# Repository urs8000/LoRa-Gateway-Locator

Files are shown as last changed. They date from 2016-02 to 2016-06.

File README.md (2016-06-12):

# LoRa-Gateway-Locator
This Node sends its position in selectable periods to all reachable gateways.
Analysing the received data on node API, where the gateway EUID is shown, 
a dotted map with the coverage of each gateway could be drawn.
made by https://github.com/gonzalocasas/ttn-coverage-tracker
**The data were also shown on JPMejier's http://ttnmapper.org/**

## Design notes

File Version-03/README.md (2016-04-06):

Based on Version 01/02
- Teensy 3.2
- GPS u-blox PAM-7Q with battary backup
- RFM95W (LoRa Radio 868MHz)
- OLED display (128x64) look careful when ordering. some have Vcc ans GND switched!
- navigation switches

this Version (03) added the following features
- debug/status LED (Common Anode RGB-LED, "Piranha diffused")
- PPS LED  (pulse per second)
- board mounted switches (wires could be connected for box mounted ones instead of them)
- second antenna connector (u.fl)
- GPS backup battery (CR1220)
- OpenLog SDcard based logger, connected via Serial3
  all sent positions will be logged, so it could be compared from where no connection to a given gateway could be established.

some explanations to the power supply:
getting the most out of 3 x 1.5V AA batteries and having stable 5V therefor I've added a xV to 5V step-up boost converter
The suggested Pololu step-up does not work correctly in contrary to the specification.
So I changed to another (bulkier) type found at eBay ( DC-DC Boost Converter Step Up 1-5V to 5V 500mA Module ) 
Because the layout is totally different, you have to solder it inbetween the batter case and the input pins and to bridge Vin-Vout.
If you plan to use a 5V power bank you just can bridge Vin and Vout and connect your supply instead of batteries to JPOWER

Tested on final boards, made by ITEAD Studio

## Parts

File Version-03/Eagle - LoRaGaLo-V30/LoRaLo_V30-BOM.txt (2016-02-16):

Stückliste exportiert aus C:/Users/urs/Documents/_Development/Eagle_Projects/LoRaLo-3/LoRaLo_V30.sch am 15.02.2016 23:42

Part                 Value           Device            Package         Description                                                                  MF MPN OC_FARNELL OC_NEWARK PROD_ID    VALUE
ANTENNA-(EDGE-MOUNT) SMA_EDGE        SMA_EDGE          SMA-EDGE        SMA Antenna Connector                                                                                                    
ANTENNA-(U.FL)       U.FL            U.FL              U.FL            SMD antenna connector- WRL-09144                                                                         CONN-09193 U.FL 
C1                   100u            CPOL-EUD          PANASONIC_D     POLARIZED CAPACITOR, European symbol                                                                                     
C4                   100n            C-EUC1206         C1206           CAPACITOR, European symbol                                                                                               
C7                   100u            CPOL-EUD          PANASONIC_D     POLARIZED CAPACITOR, European symbol                                                                                     
C8                   100u            CPOL-EUD          PANASONIC_D     POLARIZED CAPACITOR, European symbol                                                                                     
CR1220                               CH291-1220LF      CH291-1220LF    Battery Holder, SMT, 12mm                                                                                                
GPS-U-BLOX-PAM7M     U-BLOX-PAM-7Q   U-BLOX-PAM-7Q     U-BLOX-PAM-7Q                                                                                                                            
JPOWER                               M-1X02-SIP-100-40 SIP-100-02-40   MALE HEADER                                                                                                              
LED1                 RED             LED1206           LED-1206        LEDs                                                                                                                     
LED2                 white           LED1206           LED-1206        LEDs                                                                                                                     
OLED_128X64                          OLED_128X64       OLED_128X64                                                                                                                              
OPENLOG-MODULE                       MA06-1            MA06-1          PIN HEADER                                                                          unknown    unknown                   
P1                                   1,6/0,8           1,6/0,8         THROUGH-HOLE PAD                                                                                                         
P2                                   1,6/0,8           1,6/0,8         THROUGH-HOLE PAD                                                                                                         
P3                                   1,6/0,8           1,6/0,8         THROUGH-HOLE PAD                                                                                                         
R1                   130             RESISTOR1206      1206            Resistor                                                                                                                 
R2                   47              RESISTOR1206      1206            Resistor                                                                                                                 
R3                   47              RESISTOR1206      1206            Resistor                                                                                                                 
R4                   270             R-EU_M1206        M1206           RESISTOR, European symbol                                                                                                
R5                   4.7k            R-EU_M1206        M1206           RESISTOR, European symbol                                                                                                
R6                   4.7k            R-EU_M1206        M1206           RESISTOR, European symbol                                                                                                
R7                   270             R-EU_M1206        M1206           RESISTOR, European symbol                                                                                                
RGB-LED              LED_PIRANHA_5MM LED_PIRANHA_5MM   LED_PIRANHA_5MM High-brightness RGB through-hole LED, similar to that used in the Shiftbrite                                             
S-DWN                                TAC_SWITCHPTH     TACTILE-PTH     Momentary Switch                                                                                                         
S-SEL                                TAC_SWITCHPTH     TACTILE-PTH     Momentary Switch                                                                                                         
S-UP                                 TAC_SWITCHPTH     TACTILE-PTH     Momentary Switch                                                                                                         
SCHALTER                             PINHD-1X3         1X03            PIN HEADER                                                                                                               
STEP-UP-5V           POLOLU_STEP-UP  POLOLU_STEP-UP    POLOLU_STEP-UP                                                                                                                           
TEENSY-3.2                           TEENSY_3.1_DIL    TEENSY3-DIL     Teensy 3.1 or 3.2 in a DIL Layout.                                                                                       
U2                   RFM95WSMD       RFM95WSMD         RFM95W_SMD

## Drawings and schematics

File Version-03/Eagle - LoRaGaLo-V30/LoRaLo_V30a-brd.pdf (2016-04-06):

# GPS-U-BLOX-PAM7M JPOWER

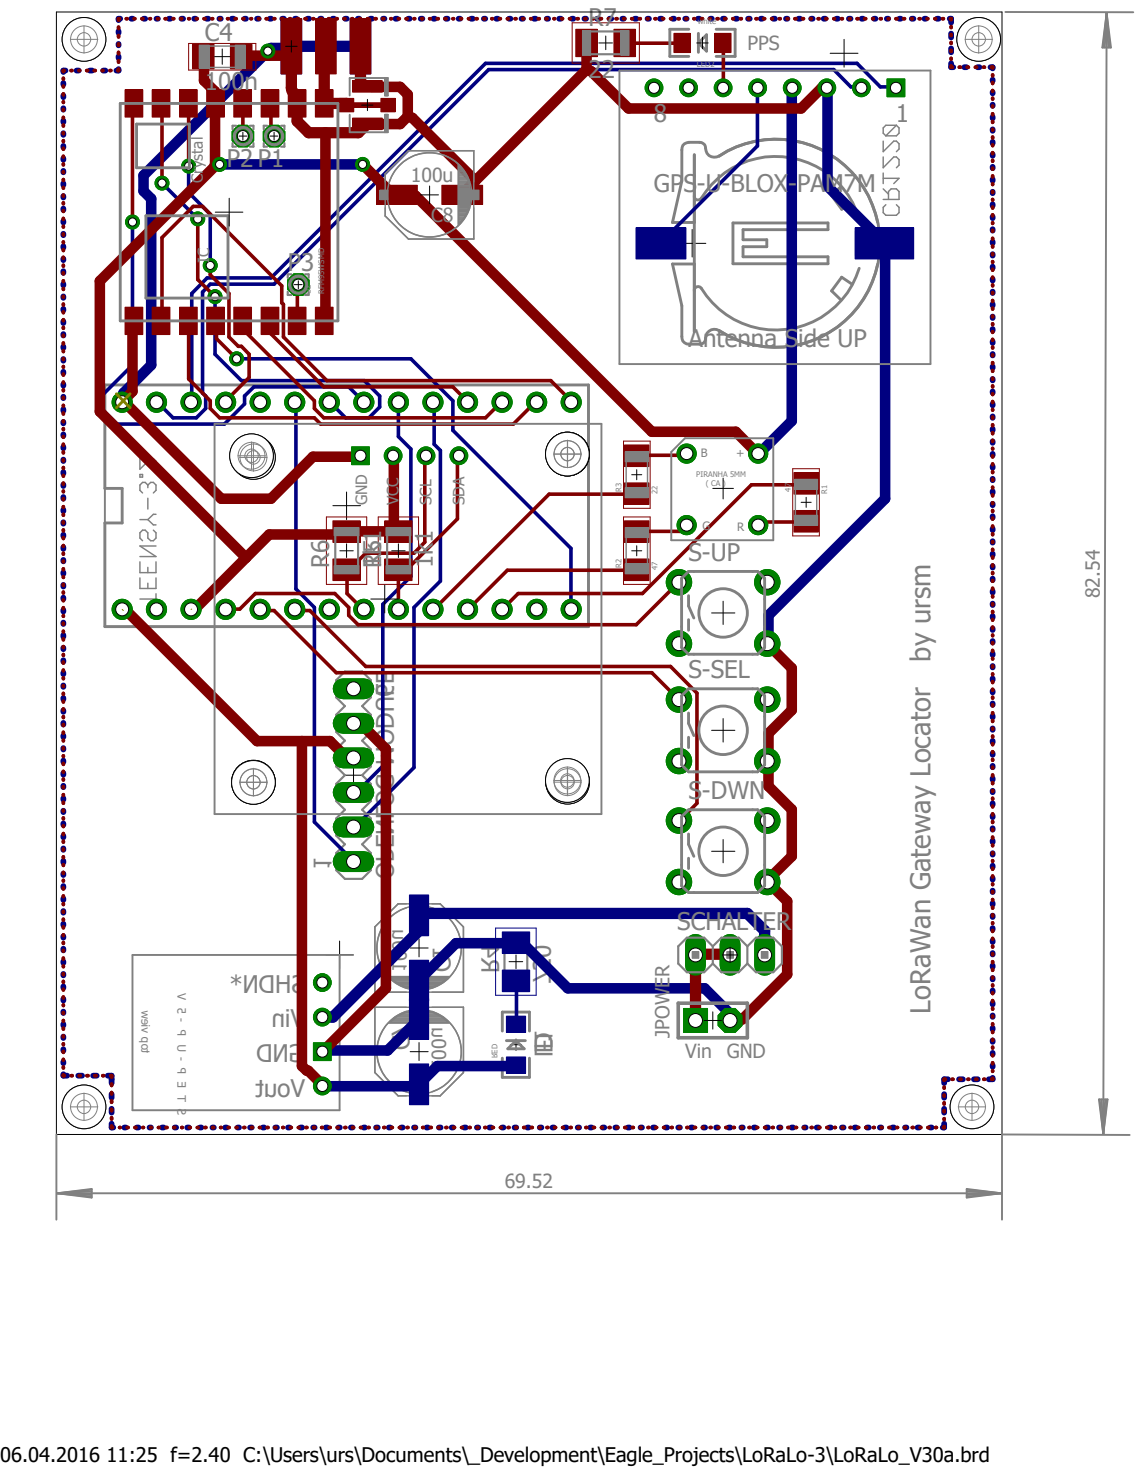
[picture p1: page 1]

LoRaWan Gateway Locator by ursm

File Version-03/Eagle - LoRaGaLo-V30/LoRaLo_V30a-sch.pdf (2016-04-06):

A

A

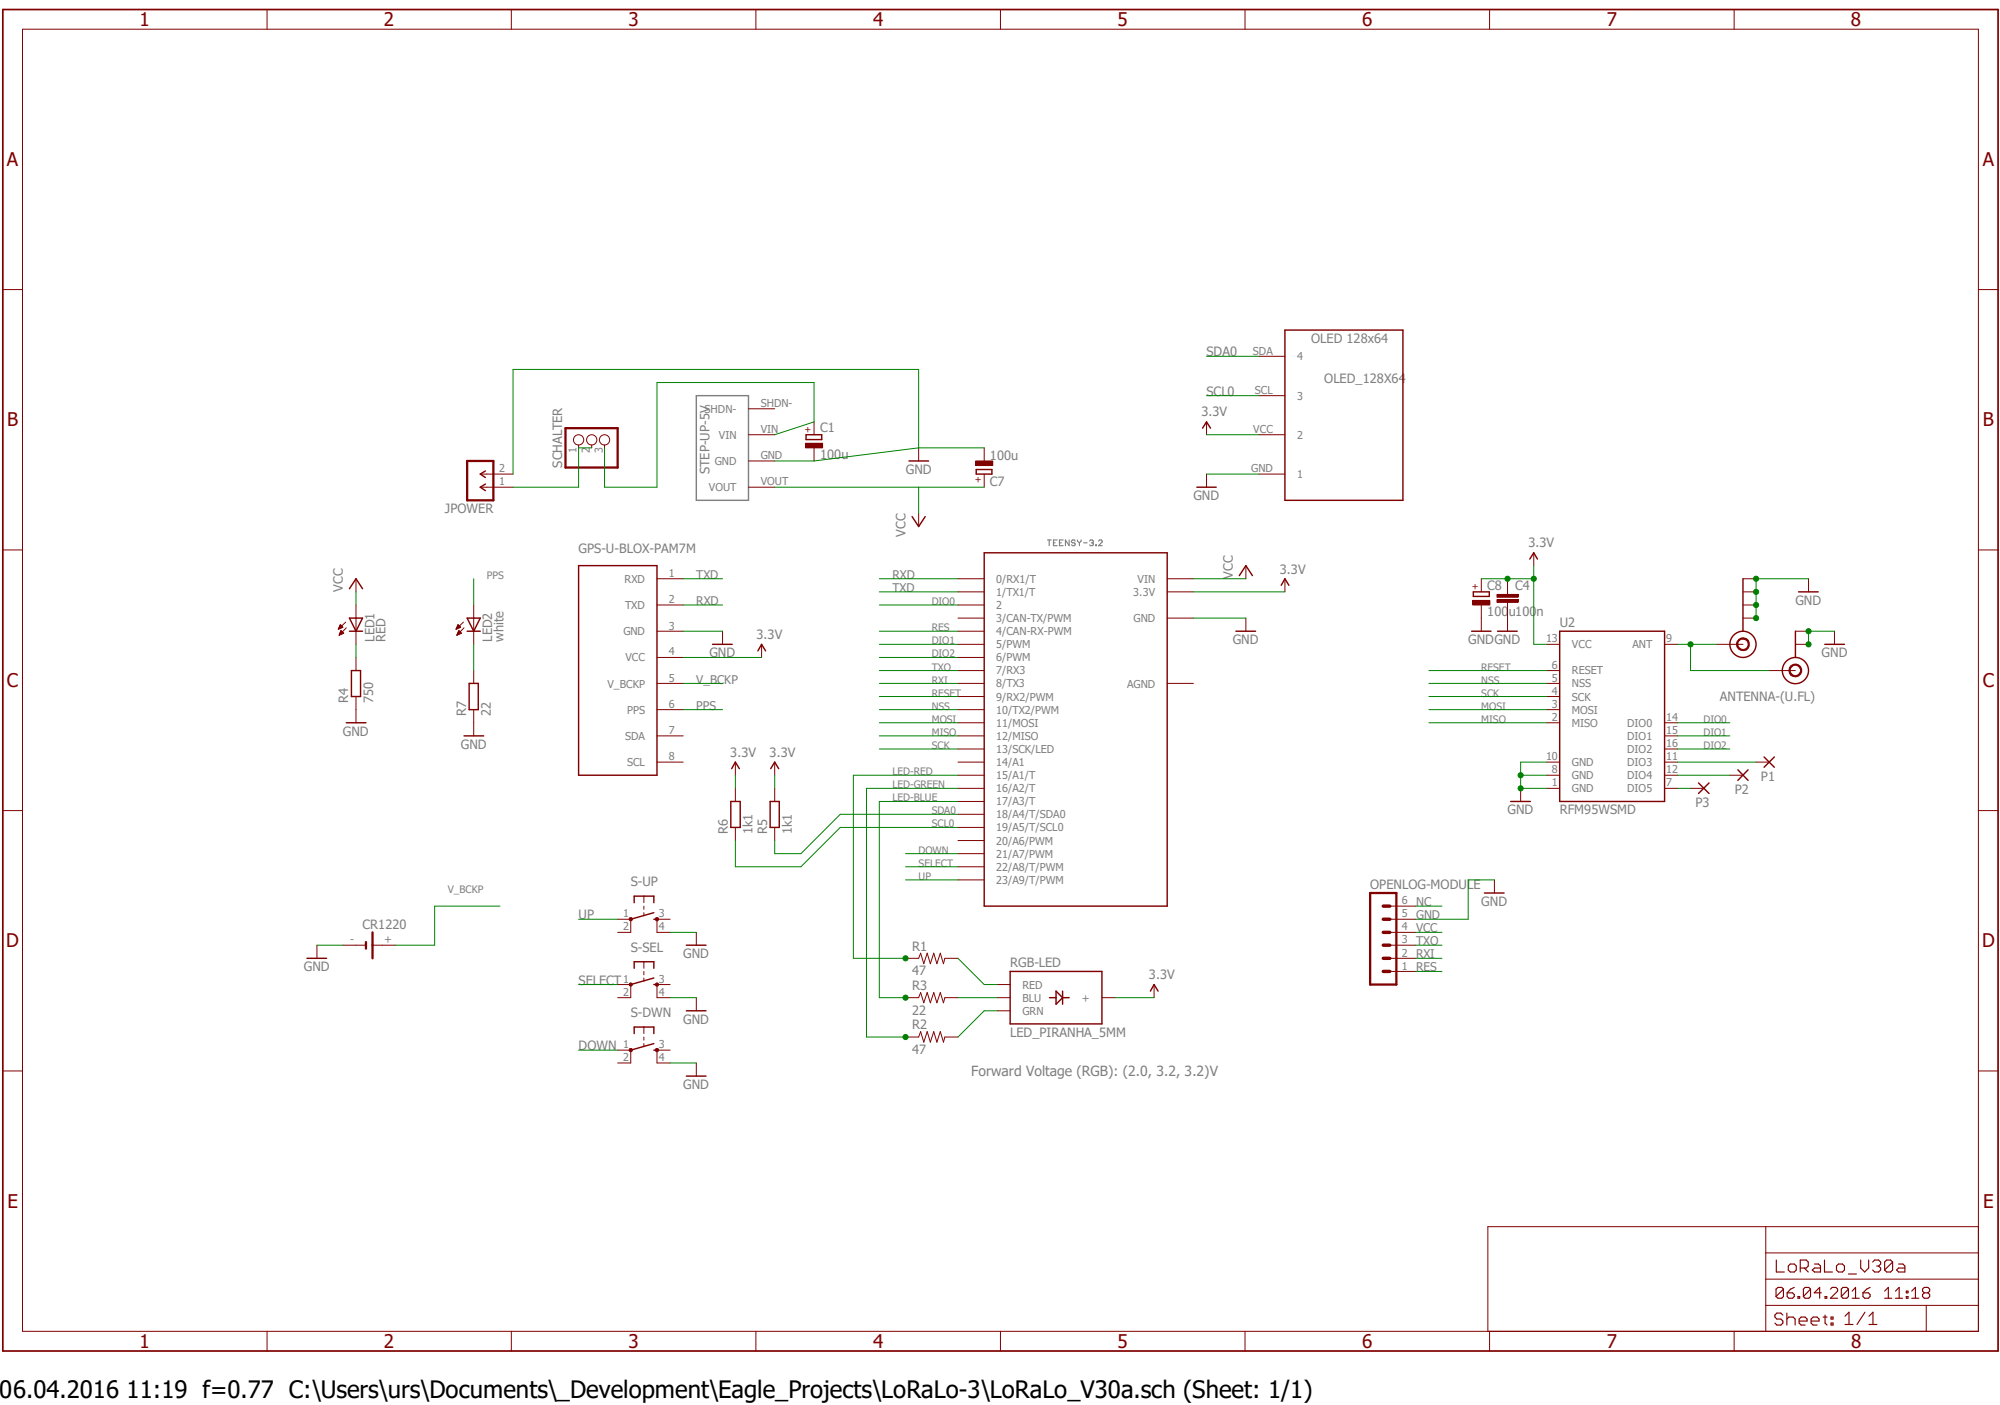
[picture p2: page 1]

06.04.2016 11:19 f=0.77 C:\Users\urs\Documents\_Development\Eagle_Projects\LoRaLo-3\LoRaLo_V30a.sch (Sheet: 1/1)

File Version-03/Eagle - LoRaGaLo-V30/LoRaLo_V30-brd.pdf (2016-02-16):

8 1

C4

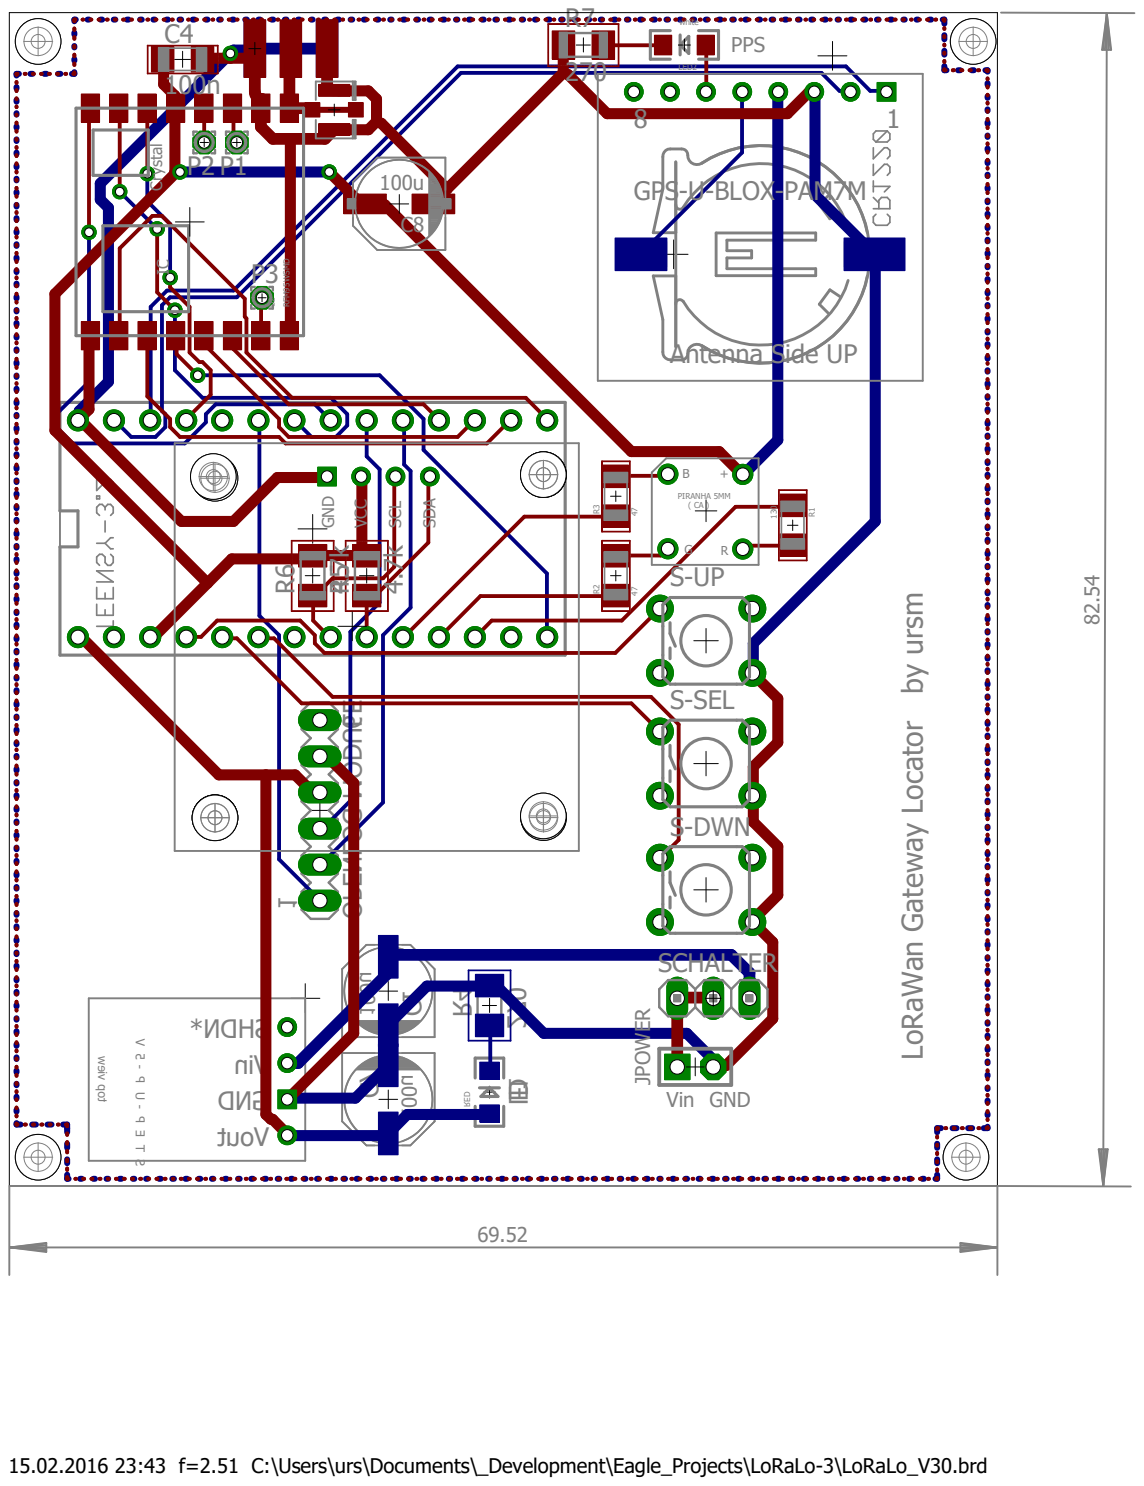
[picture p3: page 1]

LoRaWan Gateway Locator by ursm

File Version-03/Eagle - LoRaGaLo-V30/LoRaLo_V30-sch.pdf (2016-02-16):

A

A

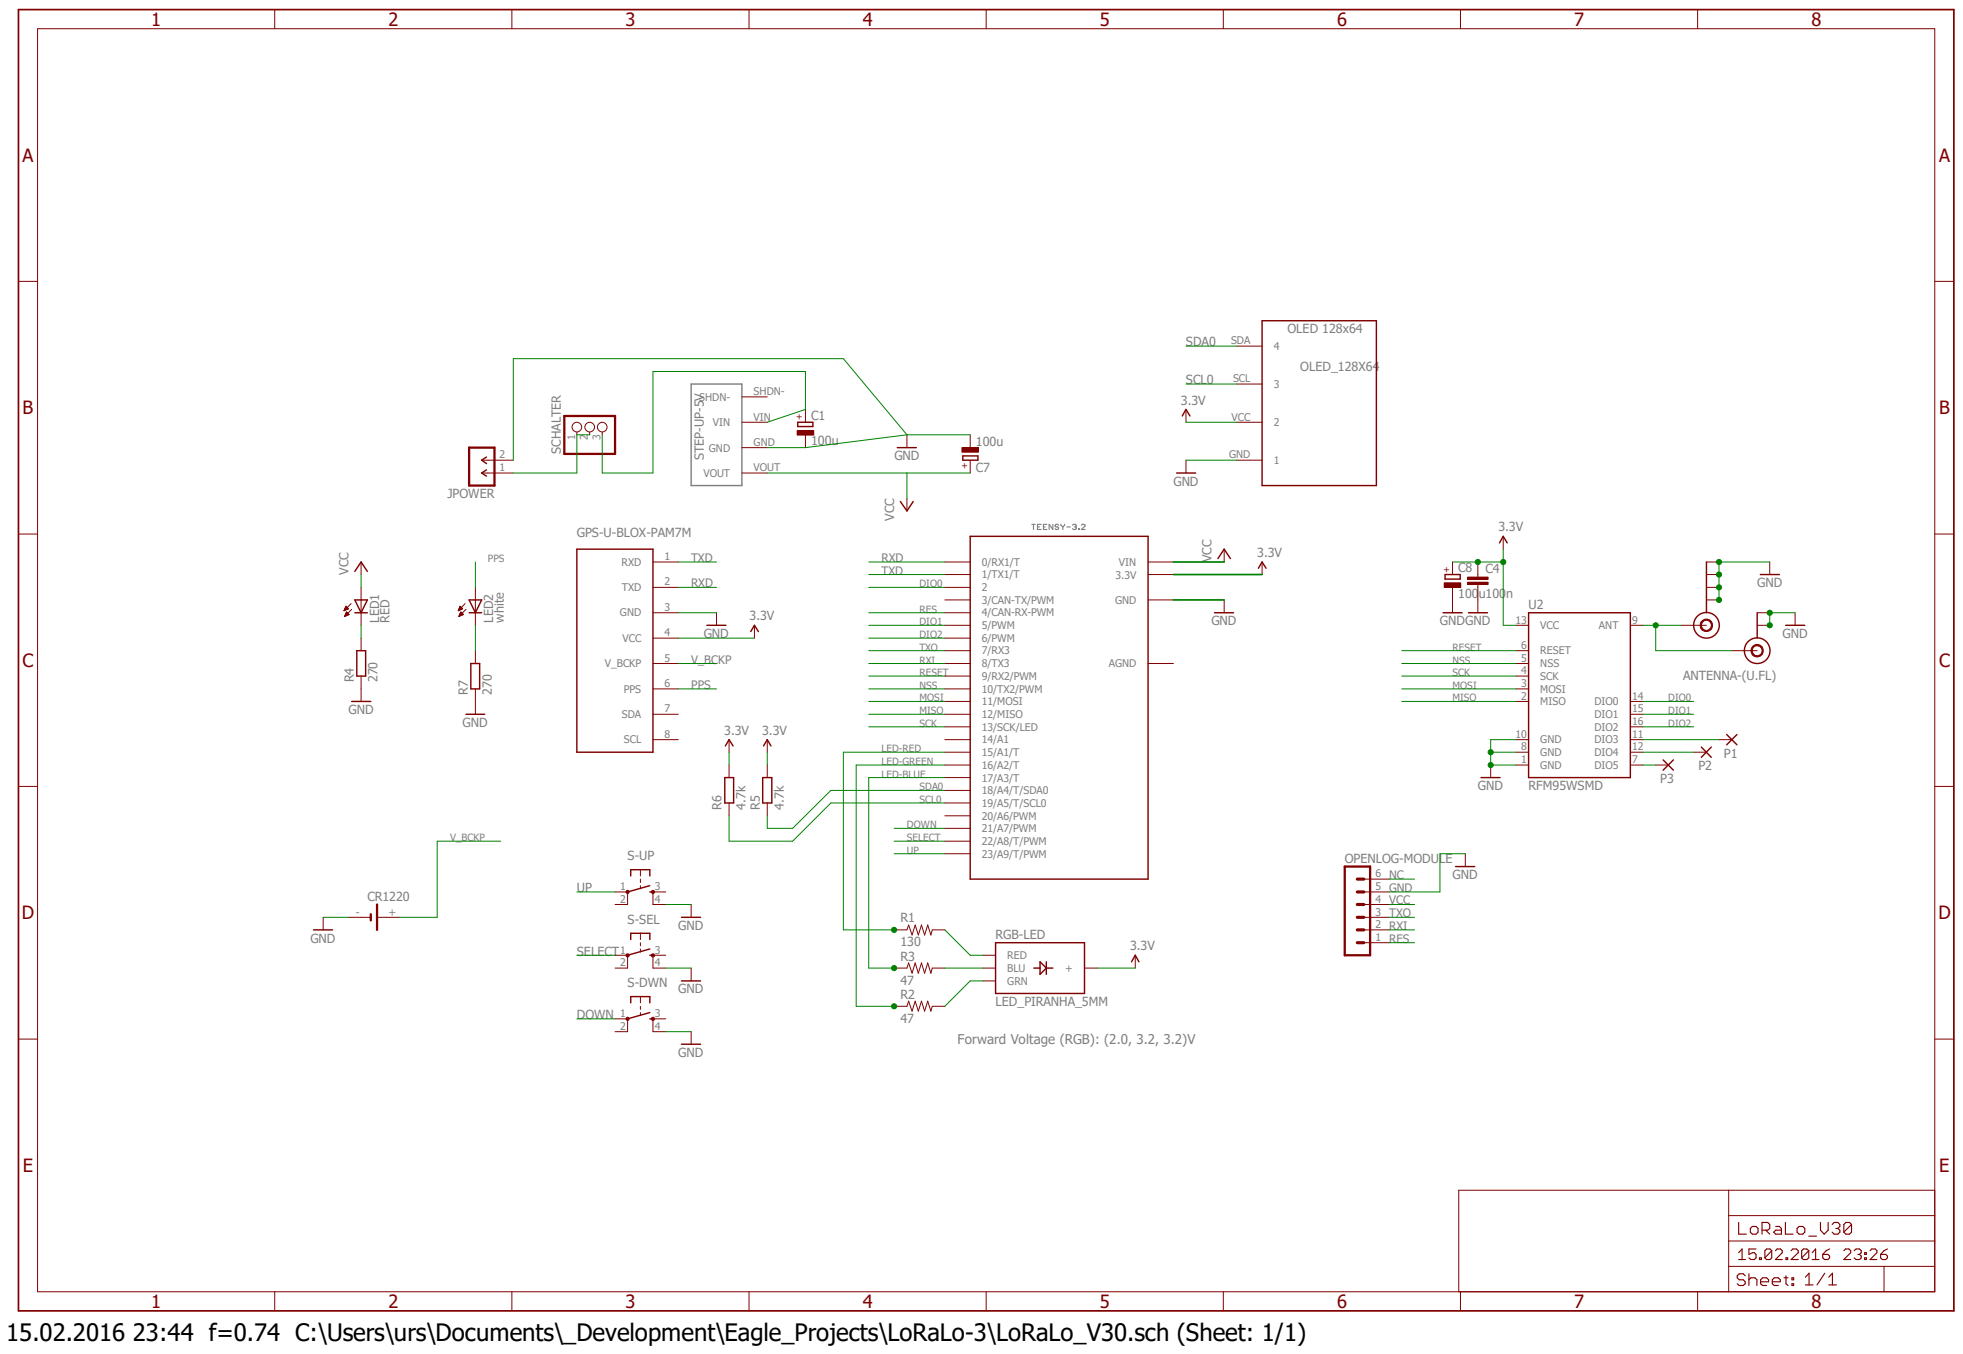
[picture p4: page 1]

15.02.2016 23:44 f=0.74 C:\Users\urs\Documents\_Development\Eagle_Projects\LoRaLo-3\LoRaLo_V30.sch (Sheet: 1/1)

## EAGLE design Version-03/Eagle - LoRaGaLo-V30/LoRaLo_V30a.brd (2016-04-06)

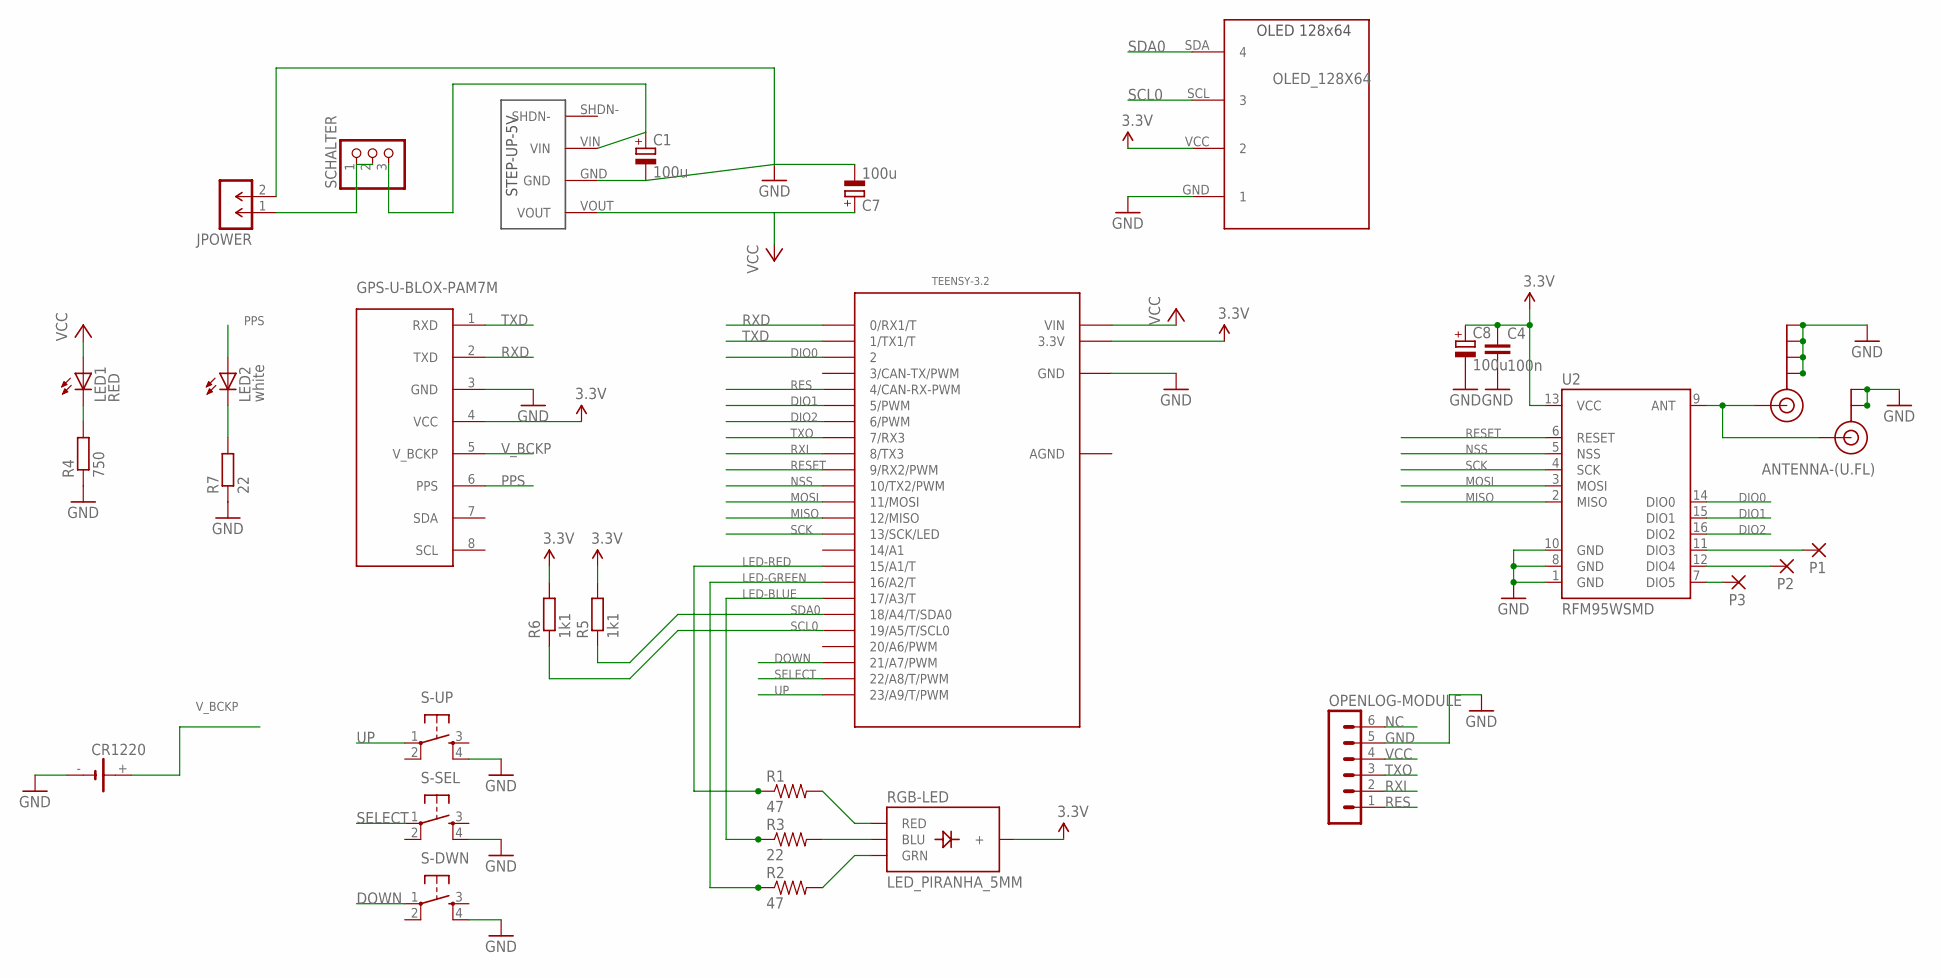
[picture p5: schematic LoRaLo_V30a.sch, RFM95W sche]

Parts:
ANTENNA-(EDGE-MOUNT): SMA_EDGE; SMA-EDGE
ANTENNA-(U.FL): U.FL
C1, C7, C8: 100u; PANASONIC_D
C4: 100n; C1206
CR1220: CH291-1220LF
GPS-U-BLOX-PAM7M: U-BLOX-PAM-7Q
JPOWER: M-1X02-SIP-100-40; SIP-100-02-40
LED1: RED; LED-1206
LED2: white; LED-1206
OLED_128X64: OLED_128X64
OPENLOG-MODULE: MA06-1
P1, P2, P3: 1,6/0,8
R1, R2: 47; 1206
R3: 22; 1206
R4: 750; M1206
R5, R6: 1k1; M1206
R7: 22; M1206
RGB-LED: LED_PIRANHA_5MM
S-DWN: TAC_SWITCHPTH; TACTILE-PTH
S-SEL: TAC_SWITCHPTH; TACTILE-PTH
S-UP: TAC_SWITCHPTH; TACTILE-PTH
SCHALTER: PINHD-1X3; 1X03
STEP-UP-5V: POLOLU_STEP-UP
TEENSY-3.2: TEENSY_3.1_DIL; TEENSY3-DIL
U2: RFM95WSMD; RFM95W_SMD

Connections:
3.3V: C4.1, C8.+, GPS-U-BLOX-PAM7M.4 (VCC), OLED_128X64.VCC (2), R5.2, R6.2, RGB-LED.+, TEENSY-3.2.3.3V, U2.13 (VCC)
AGND: TEENSY-3.2.AGND
DIO0: TEENSY-3.2.2, U2.14 (DIO0)
DIO1: TEENSY-3.2.5 (5/PWM), U2.15 (DIO1)
DIO2: TEENSY-3.2.6 (6/PWM), U2.16 (DIO2)
DOWN: S-DWN.1, TEENSY-3.2.21/A7 (21/A7/PWM)
GND: ANTENNA-(EDGE-MOUNT).GND@0 (GND), ANTENNA-(EDGE-MOUNT).GND@1 (GND), ANTENNA-(EDGE-MOUNT).GND@2 (GND), ANTENNA-(EDGE-MOUNT).GND@3 (GND), ANTENNA-(U.FL).P$1 (GND), ANTENNA-(U.FL).P$2 (GND), C1.-, C4.2, C7.-, C8.-, CR1220.-, GPS-U-BLOX-PAM7M.3 (GND), JPOWER.2, OLED_128X64.GND (1), OPENLOG-MODULE.5, R4.1, R7.1, S-DWN.4, S-SEL.4, S-UP.4, STEP-UP-5V.GND, TEENSY-3.2.GND, U2.1 (GND), U2.8 (GND), U2.10 (GND)
LED-BLUE: R3.1, TEENSY-3.2.17/A3 (17/A3/T)
LED-GREEN: R2.1, TEENSY-3.2.16/A2 (16/A2/T)
LED-RED: R1.1, TEENSY-3.2.15/A1 (15/A1/T)
MISO: TEENSY-3.2.12 (12/MISO), U2.2 (MISO)
MOSI: TEENSY-3.2.11 (11/MOSI), U2.3 (MOSI)
unnamed: R1.2, RGB-LED.R (RED)
unnamed: P1.1, U2.11 (DIO3)
unnamed: R2.2, RGB-LED.G (GRN)
unnamed: C1.+, SCHALTER.3, STEP-UP-5V.VIN
unnamed: ANTENNA-(EDGE-MOUNT).SIG (SIGNAL), ANTENNA-(U.FL).P$3 (SIGNAL), U2.9 (ANT)
unnamed: P2.1, U2.12 (DIO4)
unnamed: P3.1, U2.7 (DIO5)
unnamed: R3.2, RGB-LED.B (BLU)
unnamed: JPOWER.1, SCHALTER.1, SCHALTER.2
unnamed: LED2.C, R7.2
unnamed: LED1.C, R4.2
NC: OPENLOG-MODULE.6
NSS: TEENSY-3.2.10 (10/TX2/PWM), U2.5 (NSS)
PPS: GPS-U-BLOX-PAM7M.6 (PPS), LED2.A
RES: OPENLOG-MODULE.1, TEENSY-3.2.4 (4/CAN-RX-PWM)
RESET: TEENSY-3.2.9 (9/RX2/PWM), U2.6 (RESET)
RXD: GPS-U-BLOX-PAM7M.2 (TXD), TEENSY-3.2.0 (0/RX1/T)
RXI: OPENLOG-MODULE.2, TEENSY-3.2.8 (8/TX3)
SCK: TEENSY-3.2.13 (13/SCK/LED), U2.4 (SCK)
SCL0: OLED_128X64.SCL (3), R6.1, TEENSY-3.2.19/A5 (19/A5/T/SCL0)
SDA0: OLED_128X64.SDA (4), R5.1, TEENSY-3.2.18/A4 (18/A4/T/SDA0)
SELECT: S-SEL.1, TEENSY-3.2.22/A8 (22/A8/T/PWM)
TXD: GPS-U-BLOX-PAM7M.1 (RXD), TEENSY-3.2.1 (1/TX1/T)
TXO: OPENLOG-MODULE.3, TEENSY-3.2.7 (7/RX3)
UP: S-UP.1, TEENSY-3.2.23/A9 (23/A9/T/PWM)
VCC: C7.+, LED1.A, OPENLOG-MODULE.4, STEP-UP-5V.VOUT, TEENSY-3.2.VIN
V_BCKP: CR1220.+, GPS-U-BLOX-PAM7M.5 (V_BCKP)

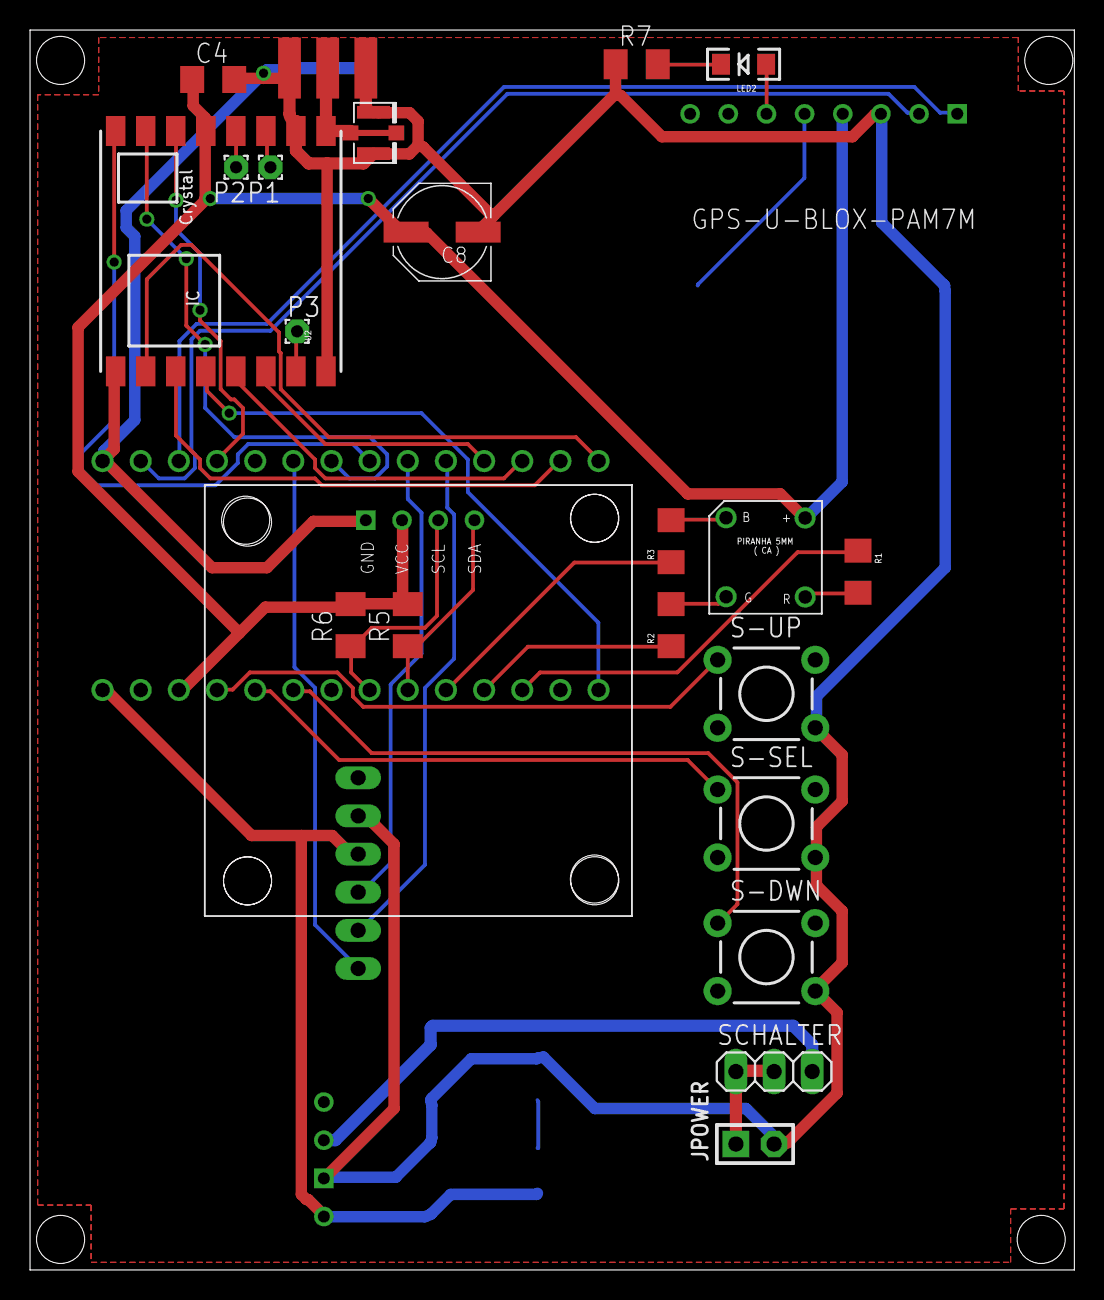
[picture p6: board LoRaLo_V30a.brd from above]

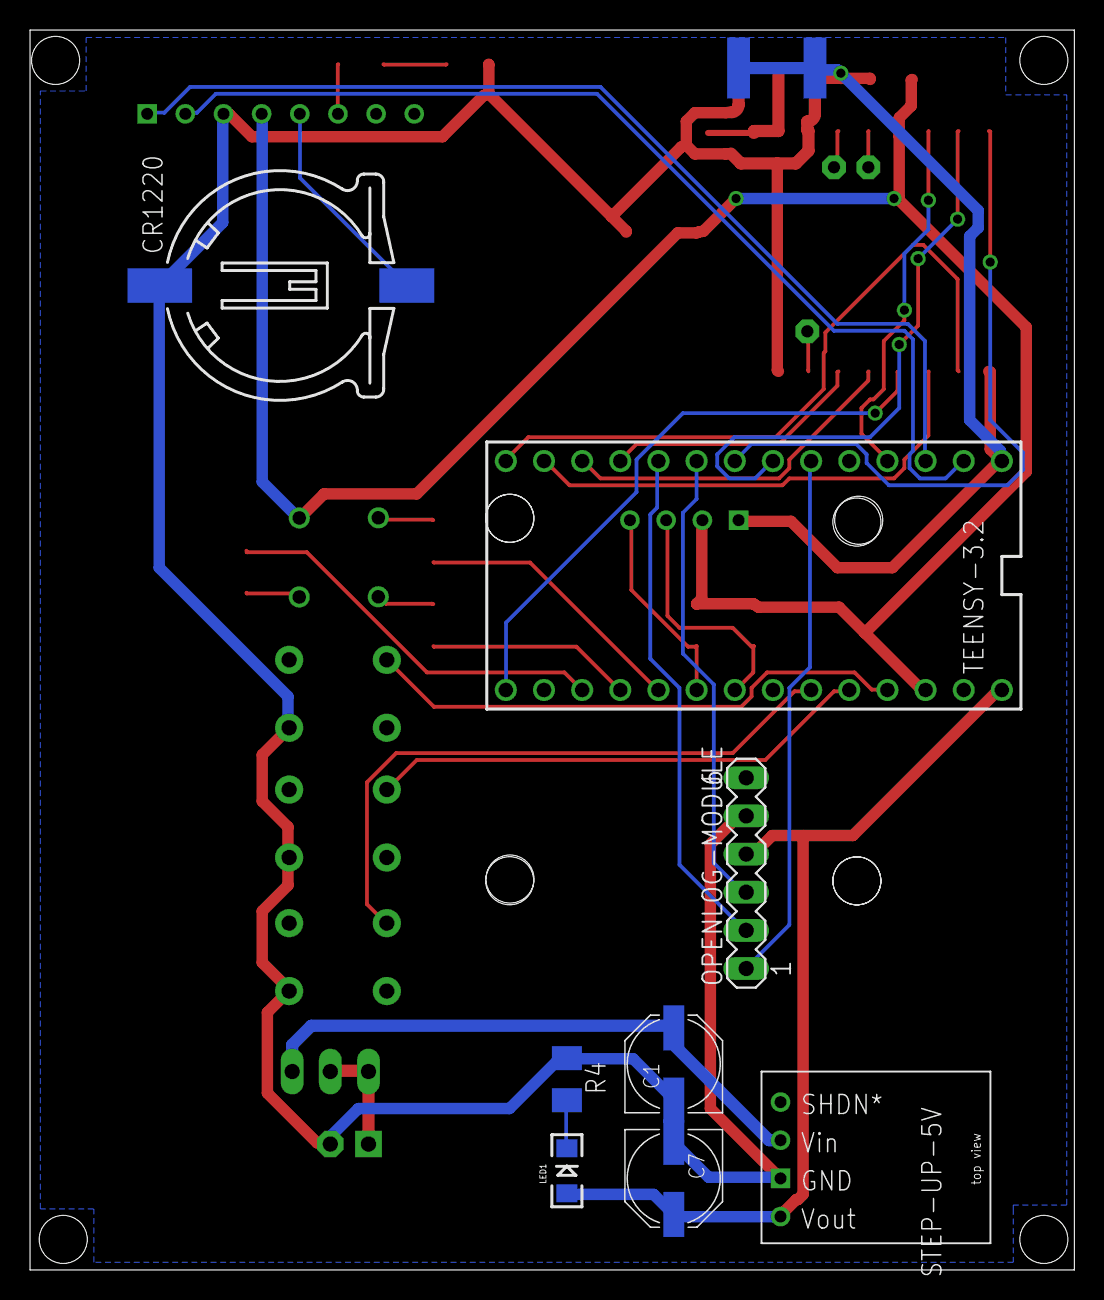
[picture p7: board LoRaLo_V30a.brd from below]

Board: 2 copper layers, 69.5 x 82.5 mm, 31 parts (8 on the bottom side), 37 nets.

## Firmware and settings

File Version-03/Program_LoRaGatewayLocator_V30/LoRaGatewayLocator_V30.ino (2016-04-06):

/*******************************************************************************
 * Copyright (c) 2015 Thomas Telkamp and Matthijs Kooijman
 *
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
 * This example sends a valid LoRaWAN packet with payload "Hello, world!", that
 * will be processed by The Things Network server.
 *
 * Note: LoRaWAN per sub-band duty-cycle limitation is enforced (1% in g1, 
*  0.1% in g2). 
 *
 * Change DEVADDR to a unique address! 
 * See http://thethingsnetwork.org/wiki/AddressSpace
 *
 * Do not forget to define the radio type correctly in config.h, default is:
 *   #define CFG_sx1272_radio 1
 * for SX1272 and RFM92, but change to:
 *   #define CFG_sx1276_radio 1
 * for SX1276 and RFM95.
 *
 * ----------------------------------------------------------------------------
 * ----------------------------------------------------------------------------
 * LoRa Gateway Locator by Urs Marti / 2016
 * this node gets it's position from a GPS
 * it runs unattended and sends its data in selectable intervals (1', 5', 10')
 * or attended on a press of a button
 * data will be displayed on an OLED display (128x64)
 * 
 * PLEASE CHANGE mydata & DEVADDR
 * adjust the size of the databuffer, depending on your Geolocation
 * each node needs a unique DEVADDR
 * 
 * OLD: this version runs with attached, but not INITIALIZED SDcard ---> see Teensy32-XBee-GPS-Board_spi_SDcard
 * NEW: Instead of waiting for the SPI "corrected" I'll use an OpenLog module
 *      much more expensive, but it seems to be the only feasible way
 *  --> It will only compiled if the define "isOpenLog" is enabled
 *  
 *  Tested with: Arduino 1.6.7 & Teensyduino on Win10 
 *  in your final compillation you should disable DEBUG1 and set GPSdebug FALSE so the code will be smaller and more efficient
 *  
 *  Hardware:  
 *  - Teensy 3.2
 *  - RFM95W  from Hoperf.nl  (compatible with SX1272)
 *  - u-blox PAM-7Q  sponsored by u-blox
 *  - OLED (blue or white) with connectors: GND - VCC - SCL - SDA  
 *         I2C 128X64 OLED Display from Aliexpress
 *  - Antenna: 868Mhz antenna module aerial 2dbi Omni direction SMA male from Aliexpress
 *  
 *  KNOWN ISSUES to be SOLVED:
 *  - menu does not go back to a defined status.
 *    reinitialize when leaving a choosen RoD
 *  - During "get Fix" it's very busy, so actions on the switches did not respond immediately   
 *  
 *
 *******************************************************************************/

#include <lmic.h>                     // https://github.com/tftelkamp/arduino-lmic-v1.5
#include <hal/hal.h>                  //
#include <SPI.h>                      //
#include <Adafruit_GPS.h>             //
#include <SoftwareSerial.h>           //
#include <Adafruit_ssd1306syp.h>      //
#include <MenuSystem.h>               // http://blog.humblecoder.com/arduino-menu-system-library/
                                      // https://github.com/jonblack/arduino-menusystem

									  
// debugging with serial monitor , comment out in final version
 #define DEBUG1

// if a OpenLog module is installed uncomment next line
// #define isOpenLog 


// Adafruit GPS or u-blox
// use Hardware RX1/TX1 on Teensy3.2
Adafruit_GPS GPS(&Serial1);

// define OLED
Adafruit_ssd1306syp display(SDA,SCL);      // for Teensy3.2  ********

#ifdef isOpenLog
  #define OpenLog Serial3                  // using HWserial on port 3 (7/8)
#endif

// Set GPSECHO to 'false' to turn off echoing the GPS data to the Serial console
// Set to 'true' if you want to debug and listen to the raw GPS sentences
#define GPSECHO  true


// Define RGB LED pins 
const int green  = 16;
const int red    = 15;
const int blue   = 17;

uint32_t timer = millis(); 
boolean HighPowerTx = false;     // set if SF12 choosen below
boolean TXcomplete  = false;     // Transaction Competed (Sent)
boolean initFix     = false;     // Initial Fix completed
boolean noFix       = true;      // no Fix yet
boolean ManButFire  = false;     // Manual Button Fire when no GPS-Fix available
boolean doRequest   = false;     // Button Request in Run on Request WITH GPS
boolean showOnce    = true;      // display menu selection once
boolean immedAction = true;      // at first selection, send immediate with no delay
char lat_buf[10];
char long_buf[10];
String DateTime;
String StatusStr;
int ManFireCntr  = 0;
String outbuf_s  = "";

// how long do we wait between measurements ?
long delayTime0    =  30000;          // 30 seconds only for debugging
long delayTime1    =  60000;          // one minute
long delayTime2    = 300000;          // five minutes
long delayTime3    = 600000;          // ten minutes
long delayTime     =  60000;          // default
long saveDelayTime = 0;               // holding the desired delay time during immediate action

// definitions for the menu and the navigation with the buttons
int KeyUp  = A9;                 // pad 23
int KeySel = A8;                 // pad 22
int KeyDwn = A7;                 // pad 21
int buttonState_Up;              // the current reading from the input pin
int lastButtonState_Up  = HIGH;  // the previous reading from the input pin
int buttonState_Sel;             // the current reading from the input pin
int lastButtonState_Sel = HIGH;  // the previous reading from the input pin
int buttonState_Dwn;             // the current reading from the input pin
int lastButtonState_Dwn = HIGH;  // the previous reading from the input pin
long debounceDelay = 50;         // the debounce time; increase if the output flickers
long lastDebounceTime_Up  = 0;   // the last time the output pin was toggled
long lastDebounceTime_Sel = 0;   // the last time the output pin was toggled
long lastDebounceTime_Dwn = 0;   // the last time the output pin was toggled
boolean MenuLevel = true;        // is true if on menu, not on sub-menu level
int MenuSelection = 0;           // 

// Menu variables
MenuSystem ms;
Menu mm("");  
MenuItem mi_SDP("Show Date/Position ");  
Menu mu_RoR("Run on Request     ");
MenuItem mi_RoR_up(" up");
MenuItem mi_RoR_Fix("RoR with Fix");
MenuItem mi_RoR_Cnt("RoR with Cnt");
Menu mu_RoDel("Run on Delay");  
MenuItem mi_Delay_up(" up");  
MenuItem mi_Delay_01(" 1 minute ");  
MenuItem mi_Delay_05(" 5 minutes");
MenuItem mi_Delay_10("10 minutes");

// Geocoordinates were shown form zero-meridian (London)/Equator = N0° 0.0 E0° 0.0 somewhere south of Ghana
// to N+90°/-90° to E+180°/-180° so the maximum rnge of mydata must be adjusted to your location
// with 14bytes it's adjusted to Europe
// Switzerland N 45..47  E 005...10
// ----------------------------1---------2---------3---------4------
//                  1234567890123456789012345678901234567890
uint8_t mydata[] = "              ";   // length see above
static osjob_t sendjob;

// Pin mapping
lmic_pinmap pins = {
  .nss = 10,                                     // Nsel/nSS  (10)
                                                 // MOSI(11), MISO(12), SCK(13) as standard
  .rxtx = 20,   // Not connected on RFM92/RFM95  // (7)  --> in case of using OpenLog canged to 20
  .rst  = 9,    // Needed on RFM92/RFM95         // (9) Reset/POR    CHANGE for XBee-Module to "8"
  .dio  = {2, 5, 6},                             // input, interrupt (2,5,6)
                                                 // 2=DIO0 , 5=DIO3 , 6=DIO4
                                                 // 3=DIO1 , 4=DIO2 = not used
};

// OpenLog definitions
int resetOpenLog           = 4;                  //This pin resets OpenLog. Connect pin 4 to pin GRN on OpenLog.
String OpenLogFileName     = "";                 // 8.3  will be crated when a GPSfix is ok
boolean OpenLogFileCreated = false;


// LoRaWAN Application identifier (AppEUI)
// Not used in this example
static const u1_t APPEUI[8]  = { 0x02, 0x00, 0x00, 0x00, 0x00, 0xEE, 0xFF, 0xC0 };

// LoRaWAN DevEUI, unique device ID (LSBF)
// Not used in this example
static const u1_t DEVEUI[8]  = { 0x42, 0x42, 0x45, 0x67, 0x89, 0xAB, 0xCD, 0xEF };

// LoRaWAN NwkSKey, network session key 
// Use this key for The Things Network
static const u1_t DEVKEY[16] = { 0x2B, 0x7E, 0x15, 0x16, 0x28, 0xAE, 0xD2, 0xA6, 0xAB, 0xF7, 0x15, 0x88, 0x09, 0xCF, 0x4F, 0x3C };

// LoRaWAN AppSKey, application session key
// Use this key to get your data decrypted by The Things Network
static const u1_t ARTKEY[16] = { 0x2B, 0x7E, 0x15, 0x16, 0x28, 0xAE, 0xD2, 0xA6, 0xAB, 0xF7, 0x15, 0x88, 0x09, 0xCF, 0x4F, 0x3C };

// LoRaWAN end-device address (DevAddr)
// See http://thethingsnetwork.org/wiki/AddressSpace
static const u4_t DEVADDR = 0xXXXXXXXX ;                        // <-- Change this address for every node!


//////////////////////////////////////////////////
// APPLICATION CALLBACKS
//////////////////////////////////////////////////

// provide application router ID (8 bytes, LSBF)
void os_getArtEui (u1_t* buf) {
    memcpy(buf, APPEUI, 8);
}

// provide device ID (8 bytes, LSBF)
void os_getDevEui (u1_t* buf) {
    memcpy(buf, DEVEUI, 8);
}

// provide device key (16 bytes)
void os_getDevKey (u1_t* buf) {
    memcpy(buf, DEVKEY, 16);
}

//---------------------------------------------------------------------
// Menu callback function
void on_menu_set_SDP(MenuItem* pMenuItem)  {
  #ifdef DEBUG1
    Serial.println("--> Show actual Date/Pos");
  #endif
  MenuSelection = 1;
  MenuLevel = true;
  showDisplay_SDP();
}
void on_menu_set_RoR(MenuItem* pMenuItem)  {
  #ifdef DEBUG1
    Serial.println("--> Sel Fix or Cnt");
  #endif
  MenuLevel = true;
}
void on_menu_set_RoR_up(MenuItem* pMenuItem)  {
  #ifdef DEBUG1
    Serial.println("--> leave RoR submenu");
  #endif
  MenuSelection = 0;
  MenuLevel = true;
  displayMenu();
}
void on_menu_set_RoR_Fix(MenuItem* pMenuItem)  {
  #ifdef DEBUG1
    Serial.println("--> Run on Request with Fix");
  #endif
  MenuSelection = 2;
  MenuLevel = false;
  showDisplay_RoR_Fix();
}
void on_menu_set_RoR_Cnt(MenuItem* pMenuItem)  {
  #ifdef DEBUG1
    Serial.println("--> Run on Request with Counter");
  #endif
  MenuSelection = 2;
  ManButFire = true;
  MenuLevel  = false;
  showDisplay_RoR_MFB();
}
void on_menu_set_RoDel(MenuItem* pMenuItem)  {
  #ifdef DEBUG1
    Serial.println("--> Select Delay");
  #endif
  MenuLevel = true;
}
void on_menu_set_DelayUp(MenuItem* pMenuItem)  {
  #ifdef DEBUG1
    Serial.println("--> leave RoD submenu");
  #endif
  MenuSelection = 0;
  MenuLevel = true;
  displayMenu();
}
void on_menu_set_Delay01(MenuItem* pMenuItem)  {
  MenuSelection = 3;
  if ( !HighPowerTx ) {
     delayTime = delayTime1;
     #ifdef DEBUG1
       Serial.print(" Delay: ");
	   Serial.println(delayTime);
     #endif
  } else {
     delayTime = delayTime2;
     #ifdef DEBUG1
       Serial.println(" High Power Tx  set, so Delay: 5 minutes");
     #endif
  }  
  MenuLevel = false;
  showDisplay_RonDel();
}
void on_menu_set_Delay05(MenuItem* pMenuItem)  {
  #ifdef DEBUG1
    Serial.println(" Delay: 5 minutes");
  #endif
  MenuSelection = 3;
  delayTime = delayTime2;
  MenuLevel = false;
  showDisplay_RonDel();
}
void on_menu_set_Delay10(MenuItem* pMenuItem)  {
  #ifdef DEBUG1
    Serial.println(" Delay: 10 minutes");
  #endif
  MenuSelection = 3;
  delayTime = delayTime3;
  MenuLevel = false;
  showDisplay_RonDel();
}

// ===================================================================================================
void setup() {

// initialize button pins (internal pullup, switch takes it LOW)
  pinMode(KeyUp,  INPUT_PULLUP);
  pinMode(KeySel, INPUT_PULLUP);
  pinMode(KeyDwn, INPUT_PULLUP);
  
// setup the LED pins as output
  pinMode(red,   OUTPUT);
  pinMode(green, OUTPUT);
  pinMode(blue,  OUTPUT);
  // blink red/blue to show that initialization begins
  blink(red);     
  blink(blue);  
  
// initialize OLED  128 wide , 64 high
  display.initialize();
  display.clear();
  display.drawLine(0,0, 127,63, WHITE);     // x,x top left y,y bottom right
  display.drawLine(127,0, 0,63, WHITE);     // x,x top left y,y bottom right
  display.update();
  delay(1000);
  display.clear();
  display.setTextSize(2);                   // Textsize 2: 10 chars per line
  display.setTextColor(WHITE);
  display.setCursor(0,0);
  display.println("INITIALIZE");
   display.setTextSize(1);                  // Textsize 1:
   display.setCursor(0,30);
   display.print("Dev-Addr: "); 
   display.print(DEVADDR, HEX);
  display.update();

  #ifdef DEBUG1
    Serial.begin(57600);                         // fast read for GPS echo
    delay(5000);
    Serial.println("Starting");
  #endif
  
// GPS initialize
  // 9600 NMEA is the default baud rate for Adafruit MTK GPS's - some use 4800
   GPS.begin(9600);
   delay(100);
  // uncomment this line to turn on RMC (recommended minimum) and GGA (fix data) including altitude
   GPS.sendCommand(PMTK_SET_NMEA_OUTPUT_RMCGGA);
  // Set the update rate
   GPS.sendCommand(PMTK_SET_NMEA_UPDATE_1HZ);   // 1 Hz update rate


  // Menu setup
  mm.add_item(&mi_SDP, &on_menu_set_SDP);             // show actual date / Position
  mm.add_menu(&mu_RoR);                               // run on request (press Select)
  mu_RoR.add_item(&mi_RoR_up,  &on_menu_set_RoR_up);      //    up one level
  mu_RoR.add_item(&mi_RoR_Fix, &on_menu_set_RoR_Fix);     //    with GPS Fix
  mu_RoR.add_item(&mi_RoR_Cnt, &on_menu_set_RoR_Cnt);     //    with Counter
  mm.add_menu(&mu_RoDel);
  mu_RoDel.add_item(&mi_Delay_up, &on_menu_set_DelayUp);  //    up one level
  mu_RoDel.add_item(&mi_Delay_01, &on_menu_set_Delay01);
  mu_RoDel.add_item(&mi_Delay_05, &on_menu_set_Delay05);
  mu_RoDel.add_item(&mi_Delay_10, &on_menu_set_Delay10);
  ms.set_root_menu(&mm);


// LMIC init
  os_init();
  // Reset the MAC state. Session and pending data transfers will be discarded.
  LMIC_reset();
  // Set static session parameters. Instead of dynamically establishing a session 
  // by joining the network, precomputed session parameters are be provided.
  LMIC_setSession (0x1, DEVADDR, (uint8_t*)DEVKEY, (uint8_t*)ARTKEY);
  // Disable data rate adaptation
  LMIC_setAdrMode(0);
  // Disable link check validation
  LMIC_setLinkCheckMode(0);
  // Disable beacon tracking
  LMIC_disableTracking ();
  // Stop listening for downstream data (periodical reception)
  LMIC_stopPingable();
  // Set data rate and transmit power (note: txpow seems to be ignored by the library)
  LMIC_setDrTxpow(DR_SF7,14);
  // LMIC_setDrTxpow(DR_SF12,14);
  // HighPowerTx = true;             // disable 1 minute RoD !!
                                     // make true if DR_SF12 is choosen.
  
    #ifdef DEBUG1
      //display.clear();
      display.setTextSize(1);
      display.setCursor(0,20);
      display.print("debug mode");
      display.setCursor(0,30);
      if ( !HighPowerTx ) 
         display.print("normal Pwr Mode");
      else  
         display.print("HIGH Pwr Mode");
      display.update();
    #endif
    #ifdef DEBUG1
      delayTime = delayTime0;                   // 
      Serial.print("Device-Addr: ");
      Serial.print(DEVADDR, HEX);
      Serial.println();
    #endif 

  #ifdef isOpenLog
     setupOpenLog();        //Resets logger and waits for the '<' I'm alive character
     display.setCursor(0,48);
     display.print("OpenLog ready");
     display.update();
     #ifdef DEBUG1
       Serial.println("OpenLog ready ...");
       gotoCommandMode();               //Puts OpenLog in command mode
       readDisk();
     #endif
   #endif
     
// do not uncomment - is for normal SDcard usage   (not implemented) 
//   http://forum.arduino.cc/index.php?topic=27986.msg207074#msg207074
// digitalWrite(SS,HIGH);      //disable device
// digitalWrite(10, HIGH);     //physical SS pin high before setting SPCR  

  //
  Serial.flush();
  // blink green/blue to show that initialization finished
  blink(green);     
  blink(blue);  

  timer = millis();
  
}
// =========================== setup finished ========================================================


// here following some subroutines -------------------------------------------------------------------
// handle LMIC ---------------------------------------------------------------------------------------
void onEvent (ev_t ev) {
    //debug_event(ev);

    switch(ev) {
      // scheduled data sent (optionally data received)
      // note: this includes the receive window!
      case EV_TXCOMPLETE:
          // use this event to keep track of actual transmissions
          #ifdef DEBUG1
            Serial.print("Event EV_TXCOMPLETE, time: ");
            Serial.println(millis() / 1000);
          #endif
          // StatusStr = "TX completed";
          StatusStr = "           done";
          showStatus();         
          TXcomplete = true;
          blink(green);
          if(LMIC.dataLen) { // data received in rx slot after tx
              //debug_buf(LMIC.frame+LMIC.dataBeg, LMIC.dataLen);
              #ifdef DEBUG1
                Serial.println("Data Received!");
              #endif
              blink(green); blink(blue); blink(green);
          }
          break;
      default:
          break;
    }
}

void do_send(osjob_t* j){
      #ifdef DEBUG1
        Serial.print("Time: ");
        Serial.println(millis() / 1000);
        // Show TX channel (channel numbers are local to LMIC)
        Serial.print("Send, txCnhl: ");
        Serial.println(LMIC.txChnl);
        Serial.print("Opmode check: ");
      #endif

    // Check if there is not a current TX/RX job running
    if (LMIC.opmode & (1 << 7)) {
      #ifdef DEBUG1
        Serial.println("OP_TXRXPEND, not sending");
      #endif
      blink(red);
        StatusStr = "TX NOT sending";
        showStatus();         
      } else {
      #ifdef DEBUG1
        Serial.println("ok");
      #endif
        StatusStr = "TX sending";
        showStatus();         
      // Prepare upstream data transmission at the next possible time.
      TXcomplete = false;
      LMIC_setTxData2(1, mydata, sizeof(mydata)-1, 0);
    }
    // Schedule a timed job to run at the given timestamp (absolute system time)
    // os_setTimedCallback(j, os_getTime()+sec2osticks(120), do_send);
         
}
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
void loop() {

   char c = GPS.read();                  // the GPS must be read continiously
    if (GPS.newNMEAreceived()) {         // otherwise the data will not be updated properly
       if (!GPS.parse(GPS.lastNMEA()))   // recognized with date/time
        return;  
    }

  if (( !initFix ) && ( !ManButFire )) {
     // #ifdef DEBUG1
     //   Serial.println("warte auf GPS-Fix oder Button");
     // #endif
     display.setCursor(0,40);
     display.print("warte auf GPS-Fix");
     display.update();  
     readUntilFix();
	 getPosition();
	 showPosition();
  }
       if ( showOnce ) {
         Serial.print("Menu Selection: ");
         Serial.print(MenuSelection);
         Serial.println();
         showOnce = false;
       }  

  if (MenuSelection != 2)    // on request do getKeypress
     Button();               // otherwise any button pressed?
  
  switch (MenuSelection) {
    case 0:
    // nothing selected or actual action breaked
       displayMenu();
       break;
	   
    case 1:
    // show actual position
       if ( immedAction ) 
		   delayTime = 100;                    // if the function is called the first time, do it immediately
	   else
           delayTime = delayTime1;     	     // set delayTime to level1 = 1 Minute	   
       if (timer > millis())  timer = millis();
       if (millis() - timer > delayTime)  {                 //  && (TXcomplete == true)   not needed
          timer = millis(); // reset the timer
         #ifdef DEBUG1
            Serial.println();
			if ( immedAction ) {
			  Serial.print("Immediate run");
			  Serial.println();
			}
			else {
              Serial.print("case 1, show actual position each ");
              Serial.print(delayTime);
              Serial.print(" msec");
              Serial.println();
			}
          #endif
          immedAction = false;
          getPosition();
          showPosition();
       }
       break;
	   
    case 2:
    // run on request
       getKeypress();
       if (doRequest == true) {
          if ( ManButFire ) {
            // uint8_t mydata[] = "Counter:     ";
            ManFireCntr++;
            char  rangeTestNumber_b[4];
            dtostrf(ManFireCntr, 3, 0, rangeTestNumber_b);
            outbuf_s = rangeTestNumber_b;
            // copy rangeTestNumber into sendbuffer
            for (int r=0; r!=outbuf_s.length(); r++)  {
              mydata[r] = outbuf_s[r];
            }
            showDisplay_RoR_MFB();
            #ifdef DEBUG1
              Serial.print("Manual;  Counter: ");
              Serial.print(ManFireCntr, 4);   
              Serial.println();
            #endif  
          }
          else {
           getPosition();
            #ifdef DEBUG1
              Serial.print("RoR with Fix");
              Serial.println();
            #endif  
          } 
          if ( !ManButFire )  showPosition();
           do_send(&sendjob);  
           // os_runloop_once();
       }  
       break;

    case 3:
    // run with selected delay
       if ( immedAction ) {
		   saveDelayTime  = delayTime;
		   delayTime      = 100;                    // if the function is called the first time, do it immediately
		   TXcomplete     = true;                   // needed to enter the loop the first time
	   }
       if (timer > millis())  timer = millis();
       if ((millis() - timer > delayTime) && (TXcomplete == true)){
          timer = millis(); // reset the timer
          immedAction = false;
		  delayTime = saveDelayTime;
          #ifdef DEBUG1
            Serial.println();
            Serial.print("case 3, run on selected delay: ");
            Serial.print(delayTime);
            Serial.print(" msec");
            Serial.println();
			if ( immedAction ) Serial.println("immedAction true");
          #endif
          getPosition();
          showPosition();
          if (noFix == false) do_send(&sendjob);
        }
       break;
	   
    default:
    // do nothing
       break;
  }

     os_runloop_once();  
}

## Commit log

2016-01-29 Version 01 with schema, board layout und the needed corrections
    this version needs two wires to run fully funcional
2016-02-14 final Version 2.0 (pre ordering)
    the Eagle files base on a breadboard implementation
    np dual layer board tested until now (14.02.2016)
    [LoRaLo_V20-1.brd, LoRaLo_V20-1.sch]
2016-02-14 tag added to the board
    [LoRaLo_V20-1.brd]
2016-02-14 some important notes in README added
    power supply
2016-02-15 one trace fixed
    [LoRaLo_V20-1.brd]
2016-02-16 V20-2 Rerouted
    a better routed board
    also 4 holes for the OLED
    [LoRaLo_V20-2.brd, LoRaLo_V20-2.sch]
2016-04-06 V20 deleted
    [LoRaLo_V30.brd, LoRaLo_V30.sch, LoRaLo_V30a.brd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]

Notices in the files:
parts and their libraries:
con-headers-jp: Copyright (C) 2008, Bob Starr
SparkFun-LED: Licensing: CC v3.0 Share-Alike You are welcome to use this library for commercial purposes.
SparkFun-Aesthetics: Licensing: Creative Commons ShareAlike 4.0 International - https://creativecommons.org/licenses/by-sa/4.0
